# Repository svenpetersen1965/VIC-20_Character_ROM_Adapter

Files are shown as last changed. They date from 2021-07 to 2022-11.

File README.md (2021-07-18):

# VIC-20 Character ROM Adapter
A character ROM adapter for the Commodore VIC-20 for 27C64...512 EPROMs. It supports the usage of the 2nd 2332 ROM chip select for address decoding (which the <a href="https://github.com/svenpetersen1965/C64-CHARSET-Adaptor-Switch">C64 Character ROM Adapter</a> does not do.

It is configurable via solder bridges and can be configured as a C64 character ROM adapter, as well. It fits all VIC-20 mainboards and all C64 mainboards. It is a good solution for the C64 short board and a working solution for the C64 long boards. It might collide with a optional kernal adapter on the long boards, though, so the recommended solution for those is still the <a href="https://github.com/svenpetersen1965/C64-CHARSET-Adaptor-Switch">C64 Character ROM Adapter</a>.

The VIC-20 Character ROM Adapter was mainly created to provide a solution for the <a href="https://www.tindie.com/products/bobsbits/vicky-twenty-commodore-vic-20-pcb-replica/">Vicky Twenty</a> VIC-20 replica.

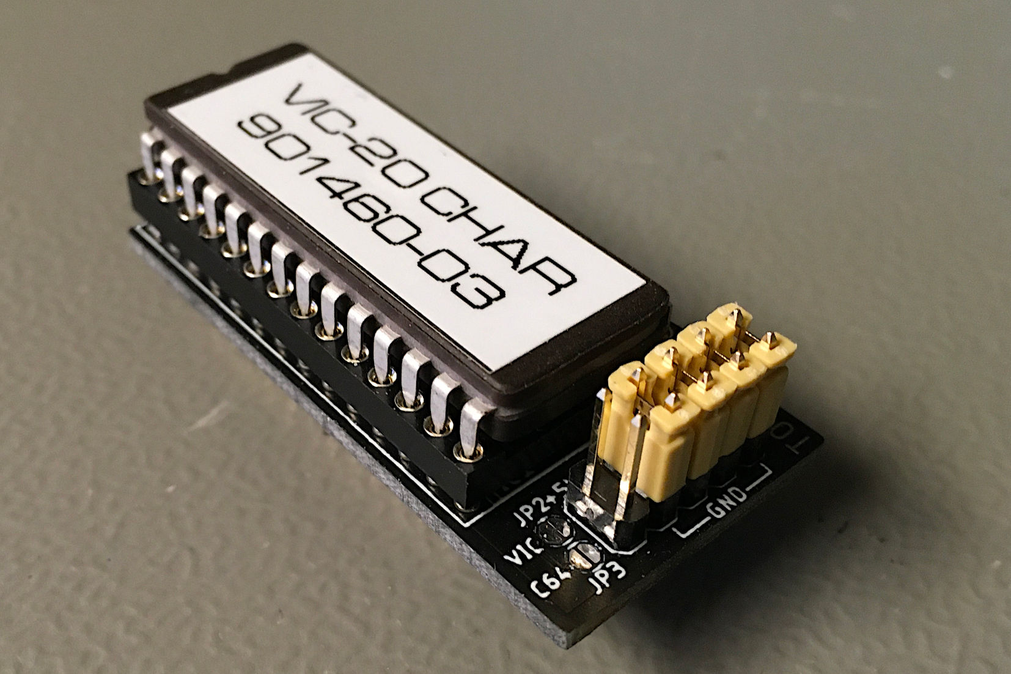
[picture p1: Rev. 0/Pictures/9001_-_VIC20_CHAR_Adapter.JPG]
VIC-20 Character ROM Adapter


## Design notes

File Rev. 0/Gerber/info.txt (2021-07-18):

      
       Board: VIC-20_CHARSET_adapter
       Rev.:  0
  
       Files:
       ======
  
       All Gerber files are generated in extended gerber format (RS274X)
       *.TOP        : Film top copper
       *.BOT        :  -"- bottom copper
       *.STC        :  -"- top soldermask 
       *.STS        :  -"- bottom soldermask
       *.PLC        :  -"- silk screen top
       *.PLS        :  -"- silk screen bottom
       *.CRC        :  -"- cream top
       *.DK         : Drills plated Through (Excellon)
       *.NDK        : Drills not plated Through (Excellon)
       *.OUT        : Board outline

       Board Size:
       ===========
       Length     :   45.0 mm
       Width      :   22.0 mm
       Thickness  :   1.6 mm
       Material   :   FR 4
       Copper     :   35 um
       Surface    :   HASL
       
       Remarks:
       ========

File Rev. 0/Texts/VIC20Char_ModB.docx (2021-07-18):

Commodore VIC-20 Character ROM Adapter Rev. 0

Module Description

The character ROM 901450-03 of the Commodore VIC-20 is a 2332 type ROM. Other than in the C64, it makes use of the 2nd chip select for address decoding. Thus, the C64 character ROM adapter (project number 126) is not suitable for the VIC-20.

The VIC-20 Character ROM adapter fixes this. Also, the geometry is different from the C64 Character ROM adapter to make it fit into ASSY250403, where it is pretty close to the RF-shield of the video circuit.

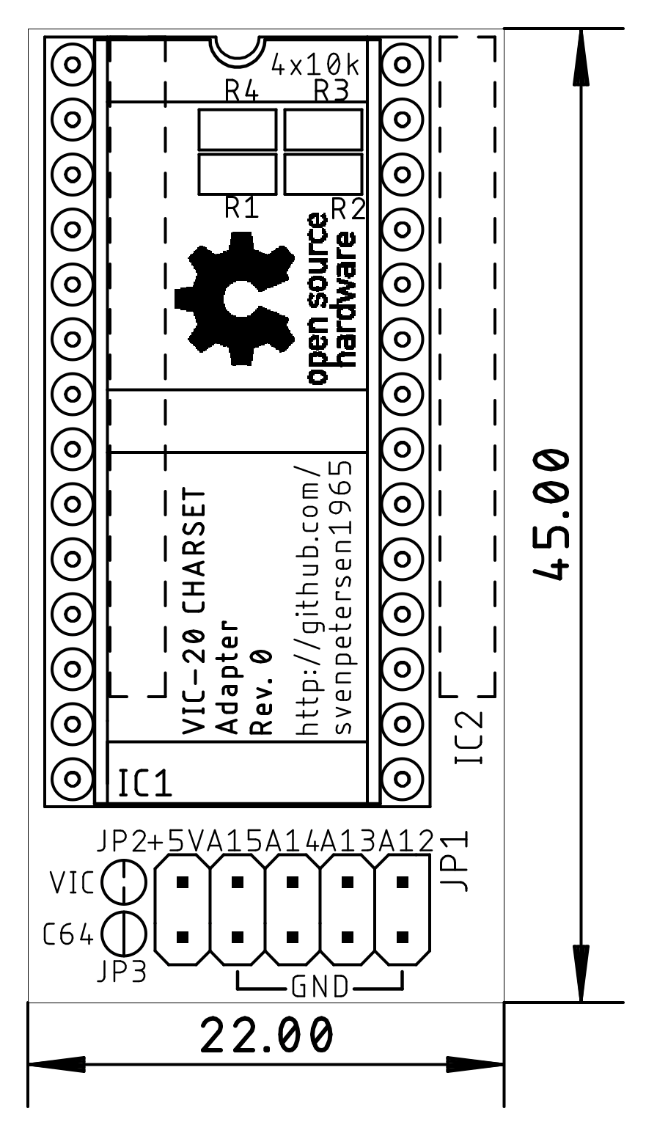
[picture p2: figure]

Figure 1: Dimensions

The VIC-20 Character ROM adapter can be configured to work with the C64 with solder bridges (JP2 & JP3). The default configuration is the VIC-20 mode, though. For the C64 short board, it fits mechanically quite well, due to the alignment of the socket/PCB to the left side or the ROM socket on the C64.

Computer | JP2 | JP3
VIC-20 | closed | open
C62 | open | closed

Table 1: Compatibility configuration

This pin-header JP1 is connected in a way, that the selection can either be accomplished with standard 2.54mm jumper bridges, DIP-switches, hex-encoding switches or a microcontroller like an Arduino etc.

Signal | Pin | Pin | Signal
A12 | 1 | 2 | GND
A13 | 3 | 4 | GND
A14 | 5 | 6 | GND
A15 | 7 | 8 | GND
+5V | 9 | 10 | n.c.

Table 2: Jumper (JP1) for Bank Selection

The +5V pin is suitable to provide supply voltage to a microcontroller.

# Bank Selection

The desired CHARACTER SET is selected at JP1. For the pinout refer to Table 2. The jumper is installed (vertically) in a way, that it connects the address line with the GND potential.

A15 | A14 | A13 | A12 | 4k Block | | Addr. Offset
set | set | set | set | | #0 | 0x0000
set | set | set | open | | #1 | 0x1000
set | set | open | set | | #2 | 0x2000
set | set | open | open | | #3 | 0x3000
set | open | set | set | | #4 | 0x4000
set | open | set | open | | #5 | 0x5000
set | open | open | set | | #6 | 0x6000
set | open | open | open | | #7 | 0x7000
open | set | set | set | | #8 | 0x8000
open | set | set | open | | #9 | 0x9000
open | set | open | set | | #10 | 0xA000
open | set | open | open | | #11 | 0xB000
open | open | set | set | | #12 | 0xC000
open | open | set | open | | #13 | 0xD000
open | open | open | set | | #14 | 0xE000
open | open | open | open | | #15 | 0xF000

Table 3: Selection of EPROM memory blocks (@JP1)

A set jumper corresponds to a LOW level (binary 0), an open jumper to a HIGH level. Do not confuse the C64 memory address and the EPROM memory address. They have the address Bit A0 to A11 in common, but the rest is different. Each of the 4k blocks appears between address $D000 and $DFFF of the C64.

# Compatibility of EPROMs

Although a 27C512 type EPROM is recommended, other types of EPROMs can be installed:

EPROM | Size | Capacity
27C64 | 8k | 2x Character Sets
27C128 | 16k | 4x Character Sets
27C256 | 32k | 8x Character Sets
27C512 | 64k | 16x Character Sets

Table 4: Capacity of EPROM types

Those EPROMs are pin compatible, the jumpers, that have no function, due to the size, have to stay open.

EPROM | Size | A15 | A14 | A13 | A12
27C512 | 64kx8 | ☑ | ☑ | ☑ | ☑
27C256 | 32kx8 | open | ☑ | ☑ | ☑
27C128 | 16kx8 | open | open | ☑ | ☑
27C64 | 8kx8 | open | open | open | ☑

Table 5: Settings per EPROM type

☑: The jumper can be open or closed, depending on the desired selection.

In case Vpp is located at a dedicated pin (pin 1), A15 has no effect anymore. A HIGH level is recommended, the corresponding jumper is open. The /PGM Pin should be set HIGH, this is accomplished by an open jumper for A14.

27C64
| 27C128
| | 27C256
| | | 27C512
| | | | SOCKET
Vpp | Vpp | Vpp | A15 | 1 | A15 | VCC | 28 | VCC | VCC | VCC | VCC
A12 | A12 | A12 | A12 | 2 | A12 | A14 | 27 | A14 | A14 | /PGM | /PGM
A7 | A7 | A7 | A7 | 3 | A7 | A13 | 26 | A13 | A13 | A13 | n.c.
A6 | A6 | A6 | A6 | 4 | A6 | A8 | 25 | A8 | A8 | A8 | A8
A5 | A5 | A5 | A5 | 5 | A5 | A9 | 24 | A9 | A9 | A9 | A9
A4 | A4 | A4 | A4 | 6 | A4 | A11 | 23 | A11 | A11 | A11 | A11
A3 | A3 | A3 | A3 | 7 | A3 | /OE | 22 | /G/Vpp | /G | /G | /G
A2 | A2 | A2 | A2 | 8 | A2 | A10 | 21 | A10 | A10 | A10 | A10
A1 | A1 | A1 | A1 | 9 | A1 | GND | 20 | /E | /E | /E | /E
A0 | A0 | A0 | A0 | 10 | A0 | D7 | 19 | D7 | D7 | D7 | D7
D0 | D0 | D0 | D0 | 11 | D0 | D6 | 18 | D6 | D6 | D6 | D6
D1 | D1 | D1 | D1 | 12 | D1 | D5 | 17 | D5 | D5 | D5 | D5
D2 | D2 | D2 | D2 | 13 | D2 | D4 | 16 | D4 | D4 | D4 | D4
GND | GND | GND | GND | 14 | GND | D3 | 15 | D3 | D3 | D3 | D3

Table 6: EPROM pin compatibility

# Using parallel EEPROMs

There are parallel EPROMs, which fit into the EPROM sockets. They do not require erasing with a UV eraser, like EPROMs, but the price is higher.

Since they can be written, which is controlled by the signal, but the Super Expander II cartridge is lacking of this functionality, this signal has to be HIGH (inactive). The 28C256 has the A14 signal connected to Pin 1, which is A15 of the EEPROM socket. This is no problem, but it has to be kept in mind, that the jumper for A15 has effect on the bank select A14 of the EPROM.

28C64
| 28C256
| | SOCKET
n.c. | A14 | 1 | A15 | VCC | 28 | VCC | VCC
A12 | A12 | 2 | A12 | A14 | 27 | /WE | /WE
A7 | A7 | 3 | A7 | A13 | 26 | A13 | n.c
A6 | A6 | 4 | A6 | A8 | 25 | A8 | A8
A5 | A5 | 5 | A5 | A9 | 24 | A9 | A9
A4 | A4 | 6 | A4 | A11 | 23 | A11 | A11
A3 | A3 | 7 | A3 | /OE | 22 | /G/Vpp | /OE
A2 | A2 | 8 | A2 | A10 | 21 | A10 | A10
A1 | A1 | 9 | A1 | GND | 20 | /E | /CE
A0 | A0 | 10 | A0 | D7 | 19 | D7 | D7
D0 | D0 | 11 | D0 | D6 | 18 | D6 | D6
D1 | D1 | 12 | D1 | D5 | 17 | D5 | D5
D2 | D2 | 13 | D2 | D4 | 16 | D4 | D4
GND | GND | 14 | GND | D3 | 15 | D3 | D3

Table 7: EEPROM pin compatibility

EEPROM | Size | A15 | A14 | A13
28C256 | 32kx8 | =A14 | OPEN | yes
28C64 | 8kx8 | OPEN | OPEN | OPEN

Table 8: Settings per EEPROM type

# Programming instructions

Character sets can be found here:

http://www.zimmers.net/anonftp/pub/cbm/firmware/computers/vic20/index.html or elsewhere. For instructions on setting up a complete multiple character ROM image, please refer to

https://github.com/svenpetersen1965/C64-Kernal-Adapter-Switch-Long-Board/blob/master/Rev.%200/pdf/C64_KernalSw_8k_v0.pdf

The description is about how to create a multiple Kernal ROM image, a multiple Character ROM image works pretty similar, except the size is only 4kB.

# Revision History

## Rev. 0

- Fully working Prototype.

VIC20Char_ModB.docx 18.07.2021 01:19 Drafted by Sven Petersen Page 2 of 2 Doc.-No.: 184-6-01-00

VIC20Char_ModB.docx 18.07.2021 01:19 Drafted by Sven Petersen Page 1 of 1 Doc.-No.: 000-6-00-00

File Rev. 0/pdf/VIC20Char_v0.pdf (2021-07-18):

# Project Documentation

## Commodore VIC-20 Character ROM Adapter

## Project number: 184

## Revision: 0

## Date: 18.07.2021

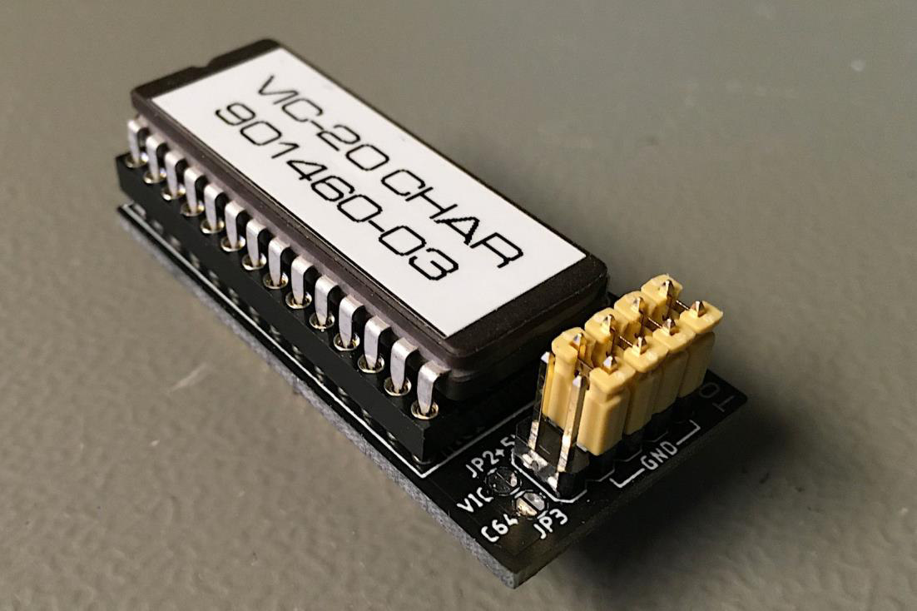
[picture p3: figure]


VIC20Char_ModB.docx | | 18.07.2021 01:19
Drafted by Sven Petersen | Page 1 of 5 | Doc.-No.: 184-6-01-00

### Commodore VIC-20 Character ROM Adapter Rev. 0

### Module Description

The character ROM 901450-03 of the Commodore VIC-20 is a 2332 type ROM. Other than in the C64, it makes use of the 2nd chip select for address decoding. Thus, the C64 character ROM adapter (project number 126) is not suitable for the VIC-20.

The VIC-20 Character ROM adapter fixes this. Also, the geometry is different from the C64 Character ROM adapter to make it fit into ASSY250403, where it is pretty close to the RF-shield of the video circuit.

Figure 1: Dimensions

The VIC-20 Character ROM adapter can be configured to work with the C64 with solder bridges (JP2 & JP3). The default configuration is the VIC-20 mode, though. For the C64 short board, it fits mechanically quite well, due to the alignment of the socket/PCB to the left side or the ROM socket on the C64.

Computer | JP2 | JP3
VIC-20 | closed | open
C62 | open | closed
Table 1: Compatibility configuration

VIC20Char_ModB.docx | | 18.07.2021 01:19
Drafted by Sven Petersen | Page 2 of 5 | Doc.-No.: 184-6-01-00

This pin-header JP1 is connected in a way, that the selection can either be accomplished with standard 2.54mm jumper bridges, DIP-switches, hex-encoding switches or a microcontroller like an Arduino etc.

Signal Pin | Pin Signal
A12 | 1 | 2 | GND
A13 | 3 | 4 | GND
A14 | 5 | 6 | GND
A15 | 7 | 8 | GND
+5V | 9 | 10 | n.c.
Table 2: Jumper (JP1) for Bank Selection

The +5V pin is suitable to provide supply voltage to a microcontroller.

## Bank Selection

The desired CHARACTER SET is selected at JP1. For the pinout refer to Table 2. The jumper is installed (vertically) in a way, that it connects the address line with the GND potential.

A15 | A14 | A13 | A12 | 4k Block | Addr. Offset
set | set | set | set | #0 | 0x0000
set | set | set | open | #1 | 0x1000
set | set | open | set | #2 | 0x2000
set | set | open | open | #3 | 0x3000
set | open | set | set | #4 | 0x4000
set | open | set | open | #5 | 0x5000
set | open | open | set | #6 | 0x6000
set | open | open | open | #7 | 0x7000
open | set | set | set | #8 | 0x8000
open | set | set | open | #9 | 0x9000
open | set | open | set | #10 | 0xA000
open | set | open | open | #11 | 0xB000
open | open | set | set | #12 | 0xC000
open | open | set | open | #13 | 0xD000
open | open | open | set | #14 | 0xE000
open | open | open | open | #15 | 0xF000
Table 3: Selection of EPROM memory blocks (@JP1)

A set jumper corresponds to a LOW level (binary 0), an open jumper to a HIGH level. Do not confuse the C64 memory address and the EPROM memory address. They have the address Bit A0 to A11 in common, but the rest is different. Each of the 4k blocks appears between address $D000 and $DFFF of the C64.

VIC20Char_ModB.docx | | 18.07.2021 01:19
Drafted by Sven Petersen | Page 3 of 5 | Doc.-No.: 184-6-01-00

## Compatibility of EPROMs

Although a 27C512 type EPROM is recommended, other types of EPROMs can be installed:

EPROM | Size | Capacity
27C64 | 8k | 2x Character Sets
27C128 | 16k | 4x Character Sets
27C256 | 32k | 8x Character Sets
27C512 | 64k | 16x Character Sets
Table 4: Capacity of EPROM types

Those EPROMs are pin compatible, the jumpers, that have no function, due to the size, have to stay open.

EPROM | Size | A15 | A14 | A13 | A12
27C512 | 64kx8 | ☑ | ☑ | ☑ | ☑
27C256 | 32kx8 | open | ☑ | ☑ | ☑
27C128 | 16kx8 | open | open | ☑ | ☑
27C64 | 8kx8 | open | open | open | ☑
Table 5: Settings per EPROM type

☑: The jumper can be open or closed, depending on the desired selection.

In case Vpp is located at a dedicated pin (pin 1), A15 has no effect anymore. A HIGH level is recommended, the corresponding jumper is open. The /PGM Pin should be set HIGH, this is accomplished by an open jumper for A14.

27C64
| 27C128
| 27C256
| 27C512
| SOCKET
Vpp | Vpp | Vpp | A15 | 1 | A15 | VCC | 28 | VCC | VCC | VCC | VCC
A12 | A12 | A12 | A12 | 2 | A12 | A14 | 27 | A14 | A14 | /PGM | /PGM
A7 | A7 | A7 | A7 | 3 | A7 | A13 | 26 | A13 | A13 | A13 | n.c.
A6 | A6 | A6 | A6 | 4 | A6 | A8 | 25 | A8 | A8 | A8 | A8
A5 | A5 | A5 | A5 | 5 | A5 | A9 | 24 | A9 | A9 | A9 | A9
A4 | A4 | A4 | A4 | 6 | A4 | A11 | 23 | A11 | A11 | A11 | A11
A3 | A3 | A3 | A3 | 7 | A3 | /OE | 22 | /G/Vpp | /G | /G | /G
A2 | A2 | A2 | A2 | 8 | A2 | A10 | 21 | A10 | A10 | A10 | A10
A1 | A1 | A1 | A1 | 9 | A1 | GND | 20 | /E | /E | /E | /E
A0 | A0 | A0 | A0 | 10 | A0 | D7 | 19 | D7 | D7 | D7 | D7
D0 | D0 | D0 | D0 | 11 | D0 | D6 | 18 | D6 | D6 | D6 | D6
D1 | D1 | D1 | D1 | 12 | D1 | D5 | 17 | D5 | D5 | D5 | D5
D2 | D2 | D2 | D2 | 13 | D2 | D4 | 16 | D4 | D4 | D4 | D4
GND | GND | GND | GND | 14 | GND | D3 | 15 | D3 | D3 | D3 | D3
Table 6: EPROM pin compatibility

VIC20Char_ModB.docx | | 18.07.2021 01:19
Drafted by Sven Petersen | Page 4 of 5 | Doc.-No.: 184-6-01-00

## Using parallel EEPROMs

There are parallel EPROMs, which fit into the EPROM sockets. They do not require erasing with a UV eraser, like EPROMs, but the price is higher.

Since they can be written, which is controlled by the WE signal, but the Super Expander II cartridge is lacking of this functionality, this signal has to be HIGH (inactive). The 28C256 has the A14 signal connected to Pin 1, which is A15 of the EEPROM socket. This is no problem, but it has to be kept in mind, that the jumper for A15 has effect on the bank select A14 of the EPROM.

28C64
| 28C256
| SOCKET
n.c. | A14 | 1 | A15 | VCC | 28 | VCC | VCC
A12 | A12 | 2 | A12 | A14 | 27 | /WE | /WE
A7 | A7 | 3 | A7 | A13 | 26 | A13 | n.c
A6 | A6 | 4 | A6 | A8 | 25 | A8 | A8
A5 | A5 | 5 | A5 | A9 | 24 | A9 | A9
A4 | A4 | 6 | A4 | A11 | 23 | A11 | A11
A3 | A3 | 7 | A3 | /OE | 22 | /G/Vpp | /OE
A2 | A2 | 8 | A2 | A10 | 21 | A10 | A10
A1 | A1 | 9 | A1 | GND | 20 | /E | /CE
A0 | A0 | 10 | A0 | D7 | 19 | D7 | D7
D0 | D0 | 11 | D0 | D6 | 18 | D6 | D6
D1 | D1 | 12 | D1 | D5 | 17 | D5 | D5
D2 | D2 | 13 | D2 | D4 | 16 | D4 | D4
GND | GND | 14 | GND | D3 | 15 | D3 | D3
Table 7: EEPROM pin compatibility
EEPROM | Size | A15 | A14 | A13
28C256 | 32kx8 | =A14 | OPEN | yes
28C64 | 8kx8 | OPEN | OPEN | OPEN
Table 8: Settings per EEPROM type

## Programming instructions

Character sets can be found here:

http://www.zimmers.net/anonftp/pub/cbm/firmware/computers/vic20/index.html or elsewhere. For instructions on setting up a complete multiple character ROM image, please refer to

https://github.com/svenpetersen1965/C64-Kernal-Adapter-Switch-Long-Board/blob/master/Rev.%200/pdf/C64_KernalSw_8k_v0.pdf (https://github.com/svenpetersen1965/C64-Kernal-Adapter-Switch-Long-Board/blob/master/Rev.%200/pdf/C64_KernalSw_8k_v0.pdf)

The description is about how to create a multiple Kernal ROM image, a multiple Character ROM image works pretty similar, except the size is only 4kB.

VIC20Char_ModB.docx | | 18.07.2021 01:19
Drafted by Sven Petersen | Page 5 of 5 | Doc.-No.: 184-6-01-00

## Revision History

### Rev. 0

- Fully working Prototype.

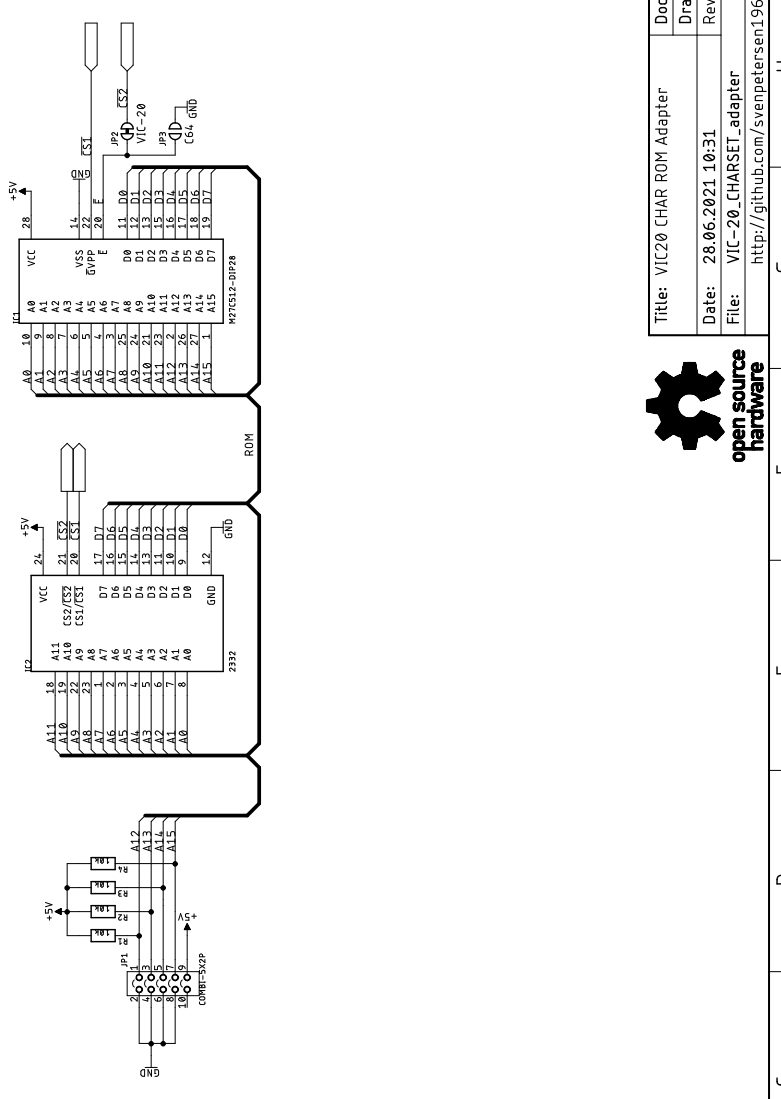
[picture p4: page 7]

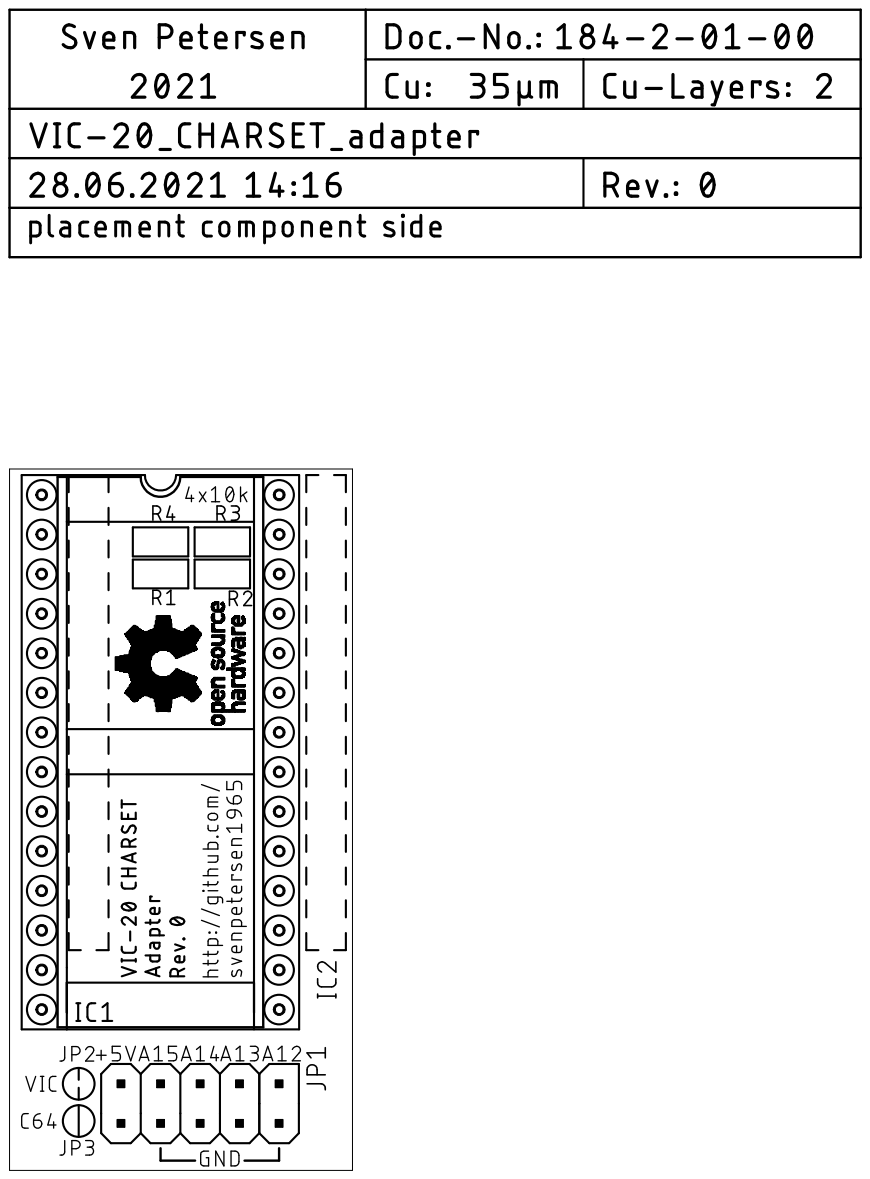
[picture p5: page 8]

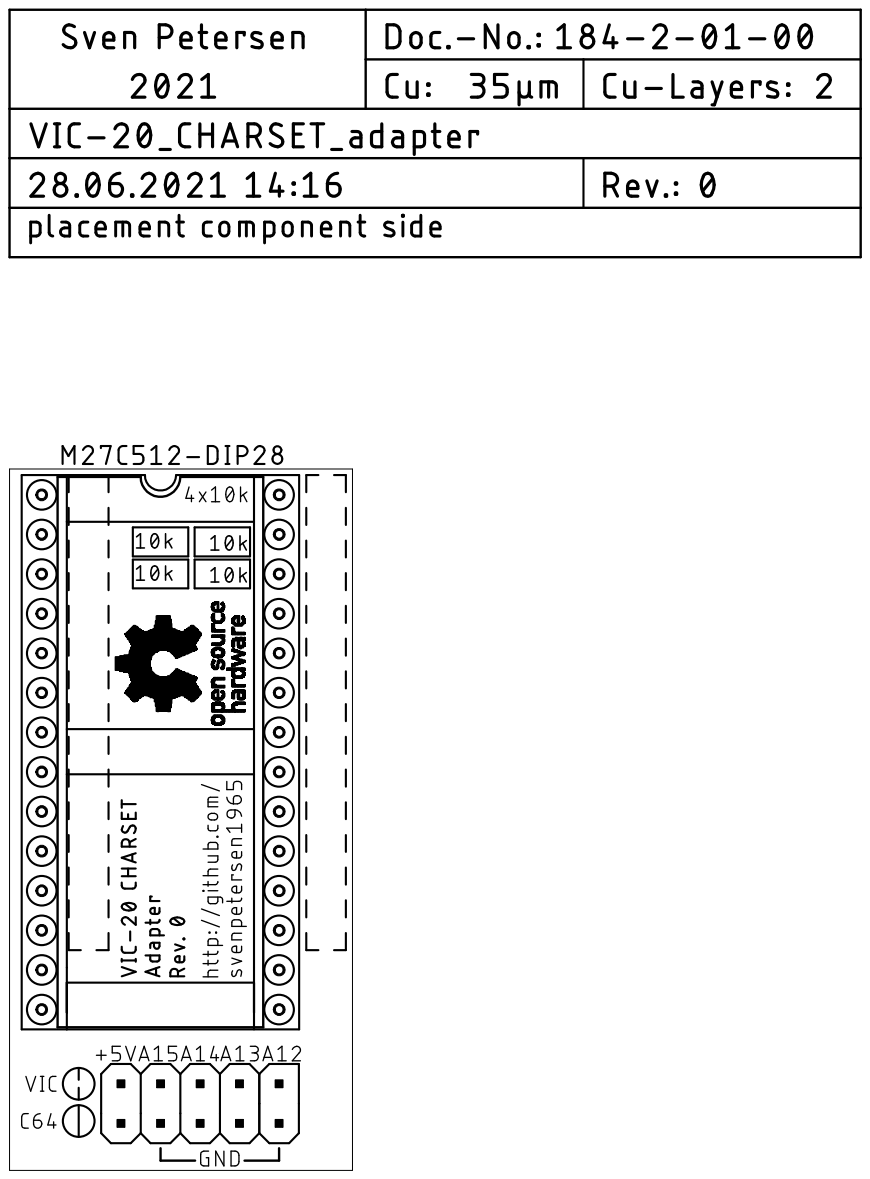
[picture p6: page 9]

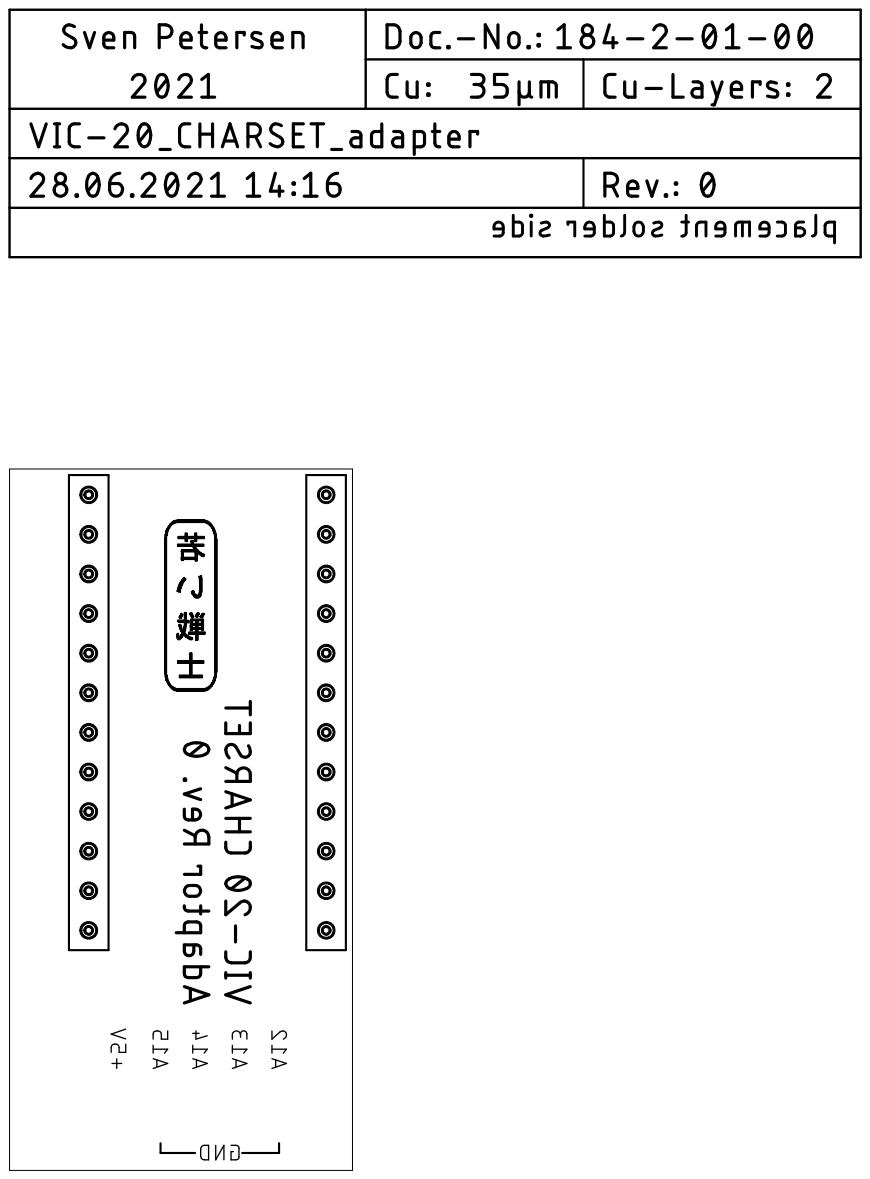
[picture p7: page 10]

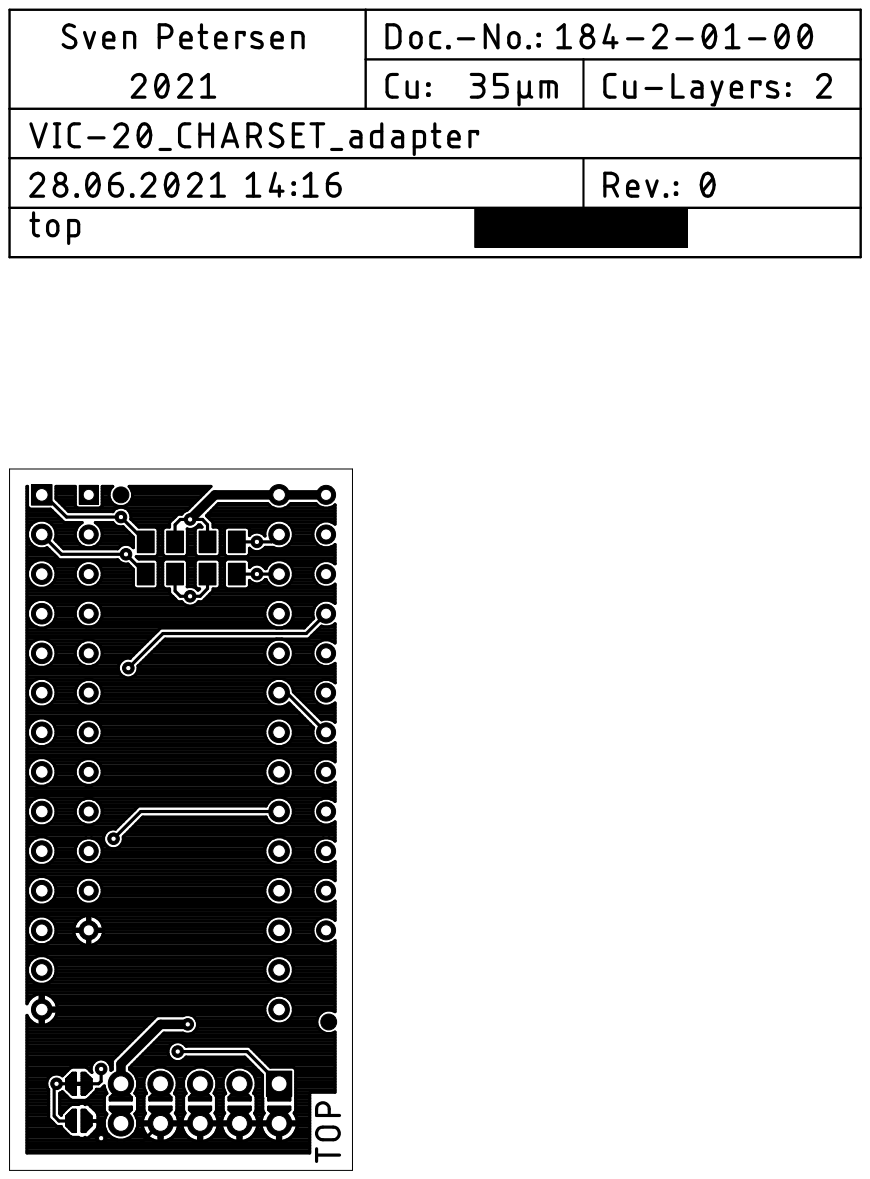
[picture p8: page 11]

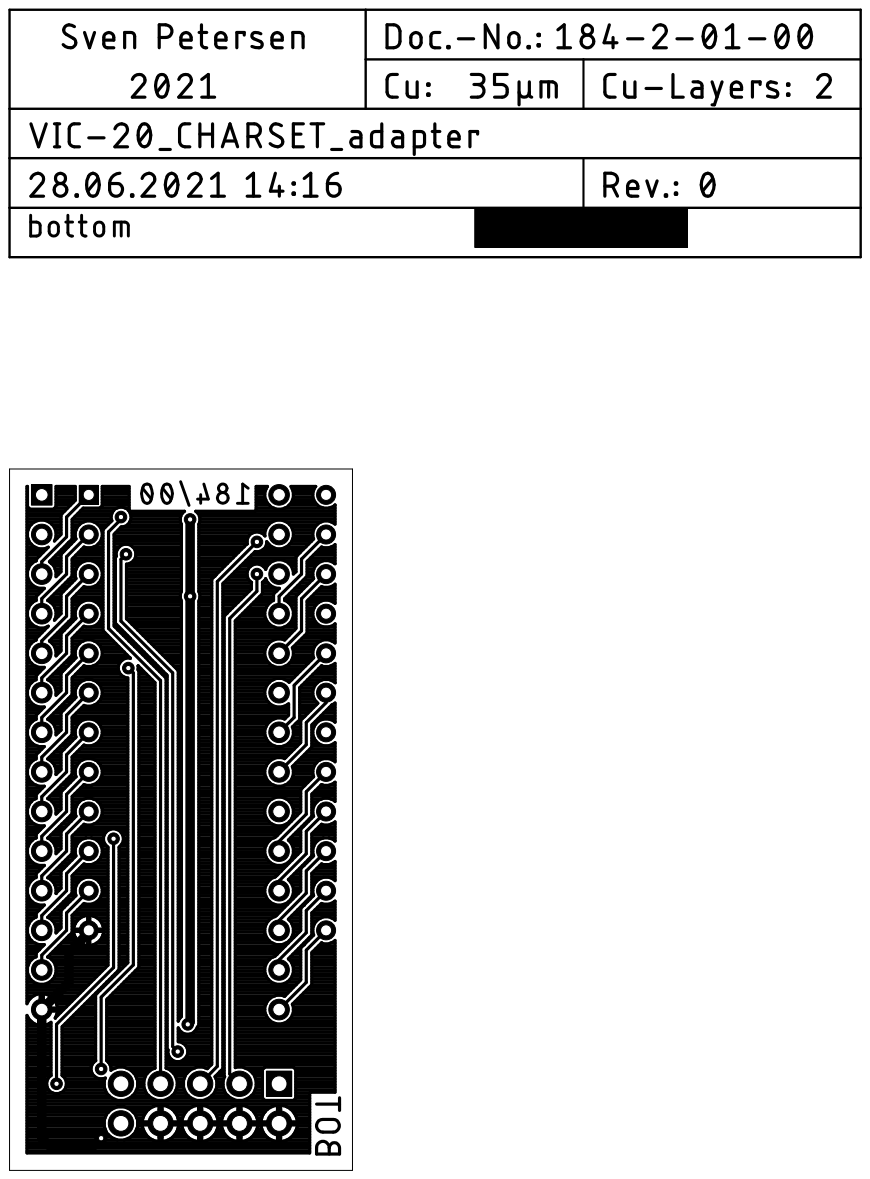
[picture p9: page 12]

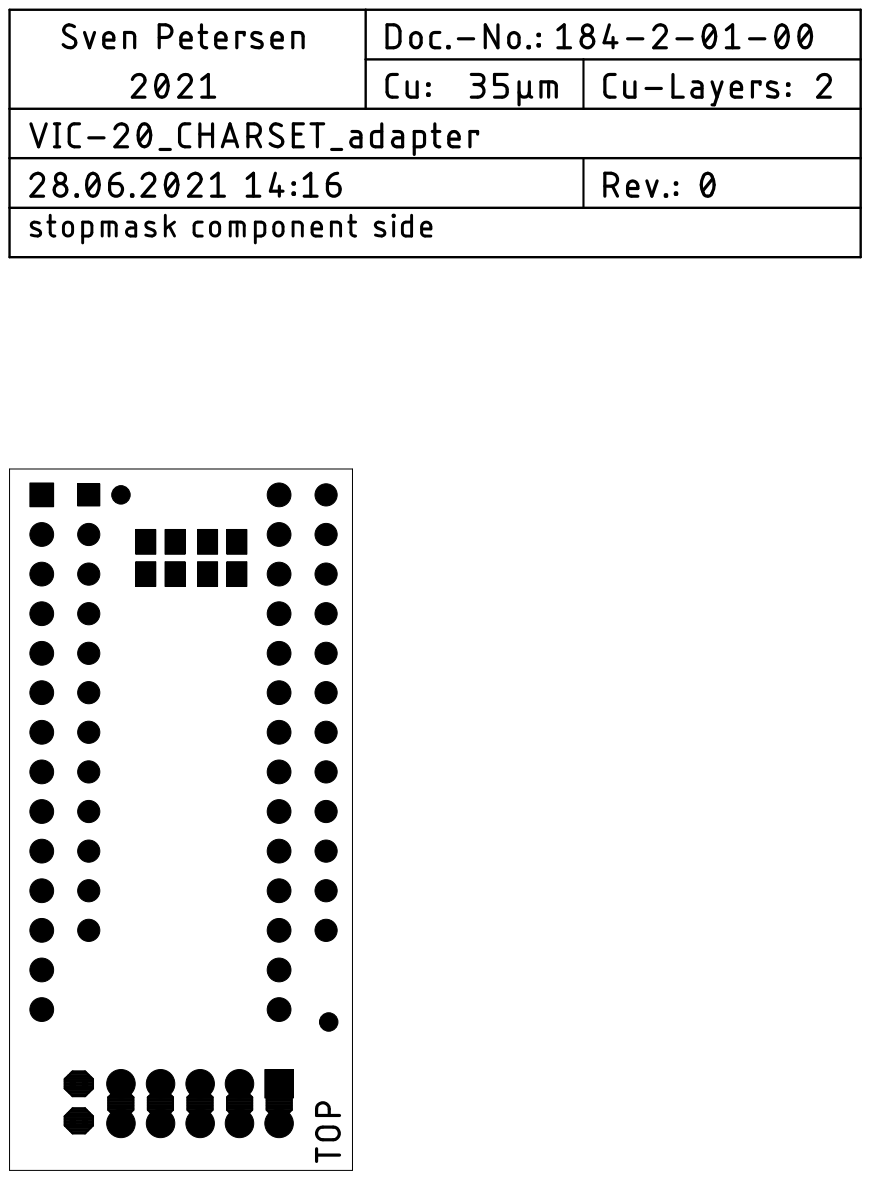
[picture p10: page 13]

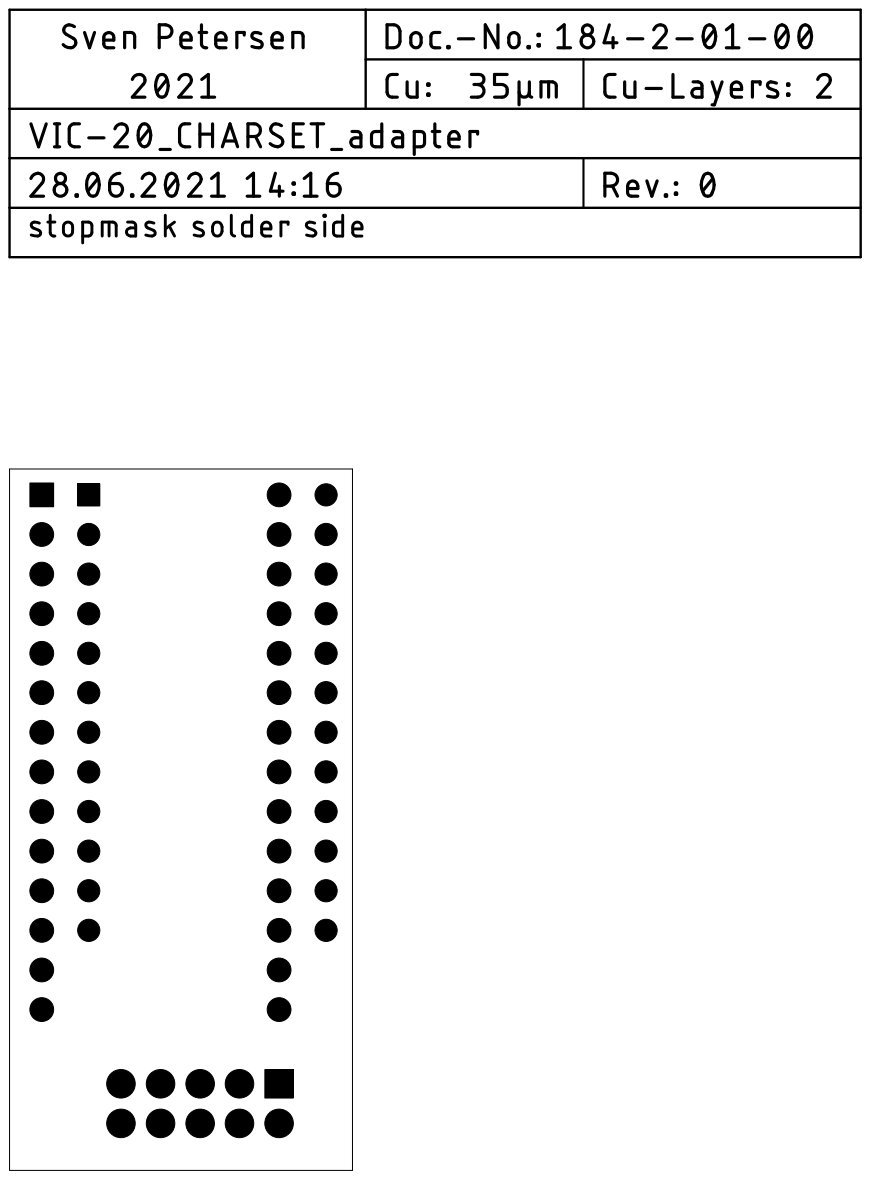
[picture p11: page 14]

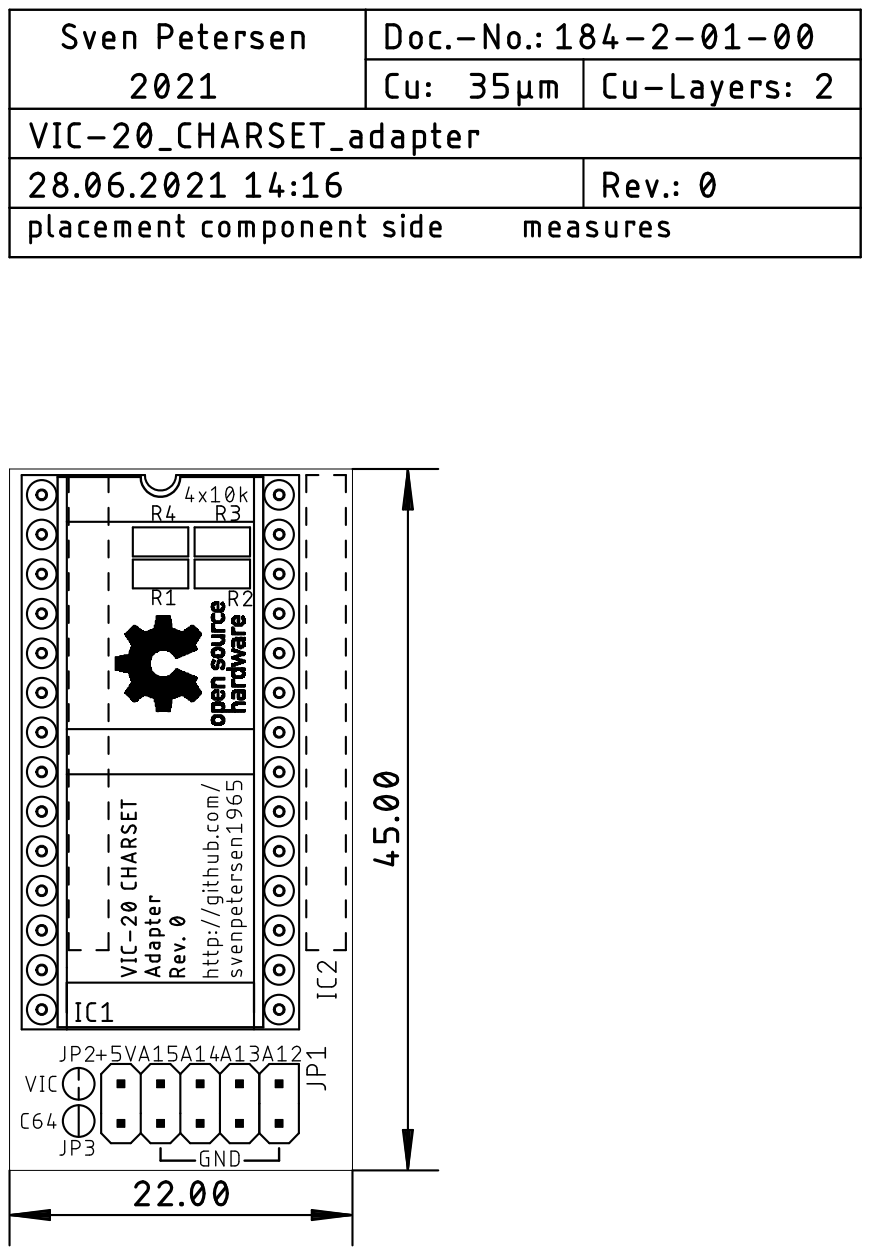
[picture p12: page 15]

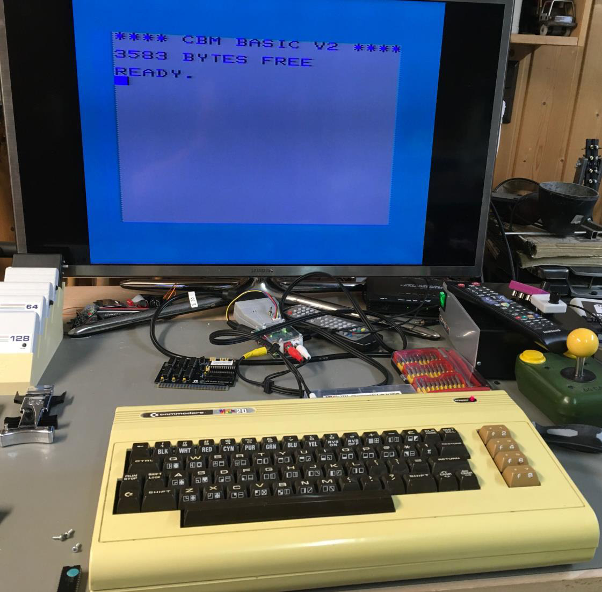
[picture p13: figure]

VIC20Char_Test.docx | | 18.07.2021 13:20
Drafted by Sven Petersen | Page 1 of 6 | Doc.-No.: 184-6-02-00

### Commodore VIC-20 Character ROM Adapter Rev. 0

### Test

## Test Setup

The Character ROM adapter Rev. 0 was electrically tested in two VIC-20:

### 1. A Vicky Twenty, which is a clone of ASSY250403 (the VIC-20 CR) 2. An original ASSY324003 (two prong VIC-20)

It was further mechanically tested in an original (non-functional) ASSY250403 with shield around the video circuit.

Finally, the adapter was reconfigured as a C64 adapter and tested with an

- ASSY250469 (short board)
- ASSY250425 (long board)

Figure 1: Test Setup with an ASSY324003 VIC-20

The screen shots were taken with a (cheap) CSL USB 2.0 Video Grabber.

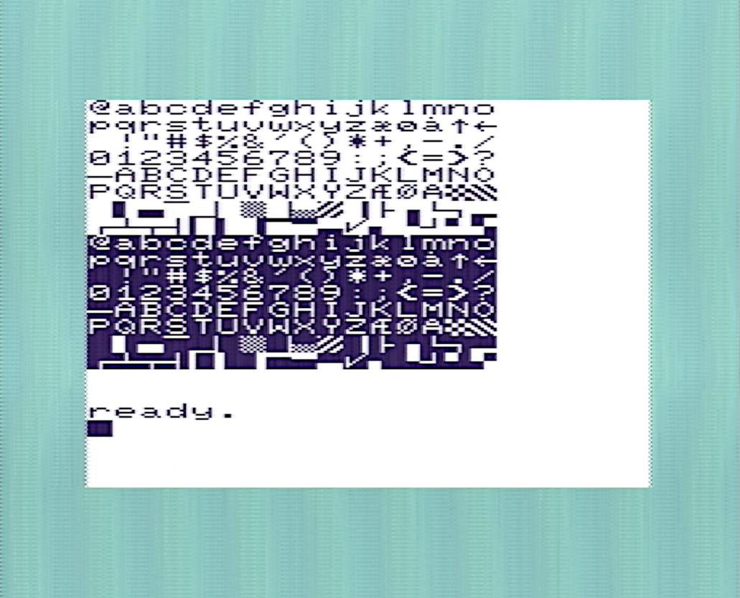
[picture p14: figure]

VIC20Char_Test.docx | | 18.07.2021 13:20
Drafted by Sven Petersen | Page 2 of 6 | Doc.-No.: 184-6-02-00

## Test Execution

### Electrical testing

A ST 27C512 EPROM (120ns) was programmed with the original Commodore character sets:

- English/International
- Danish
- Swedish/Finnish
- VC-1001

Then installed in the Vicky Twenty. A test software was written, which puts all 256 characters on the screen.

The characters were displayed properly. Pulling/stetting jumpers resulted in switching character sets (the characteristic umlauts of the particular language became visible).
The special Japanese characters became visible when switching to upper/lower case characters.

Figure 2: Danish character set on a VIC-20

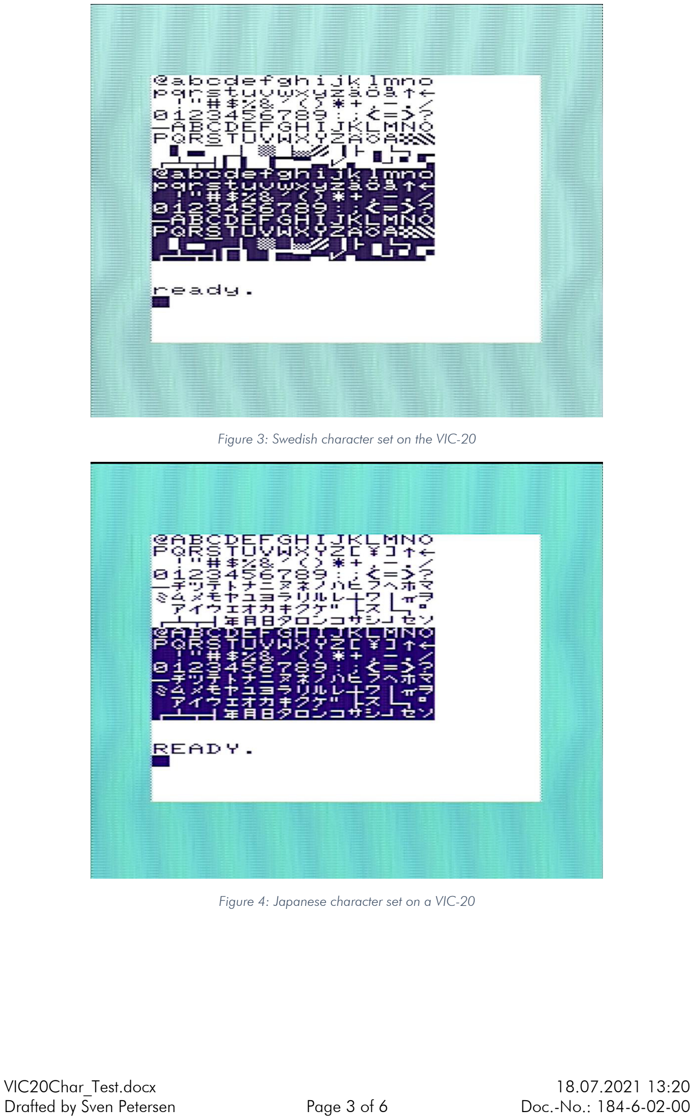
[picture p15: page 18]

VIC20Char_Test.docx | | 18.07.2021 13:20
Drafted by Sven Petersen | Page 3 of 6 | Doc.-No.: 184-6-02-00

Figure 3: Swedish character set on the VIC-20

Figure 4: Japanese character set on a VIC-20

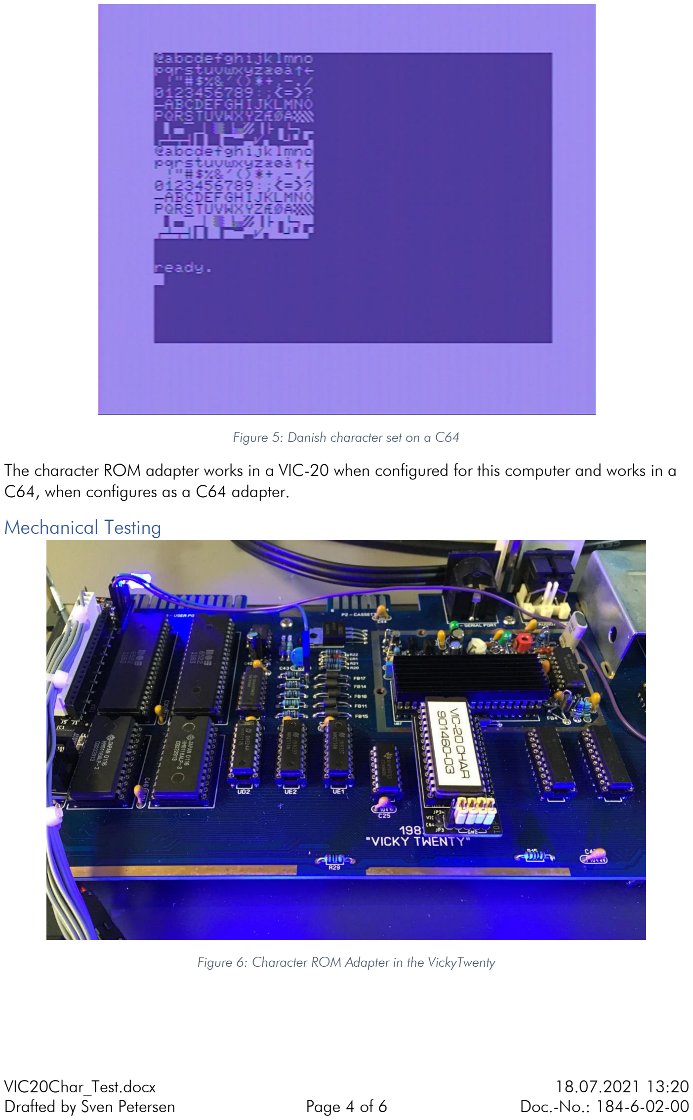
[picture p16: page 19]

VIC20Char_Test.docx | | 18.07.2021 13:20
Drafted by Sven Petersen | Page 4 of 6 | Doc.-No.: 184-6-02-00

Figure 5: Danish character set on a C64

The character ROM adapter works in a VIC-20 when configured for this computer and works in a C64, when configures as a C64 adapter.

### Mechanical Testing

Figure 6: Character ROM Adapter in the VickyTwenty

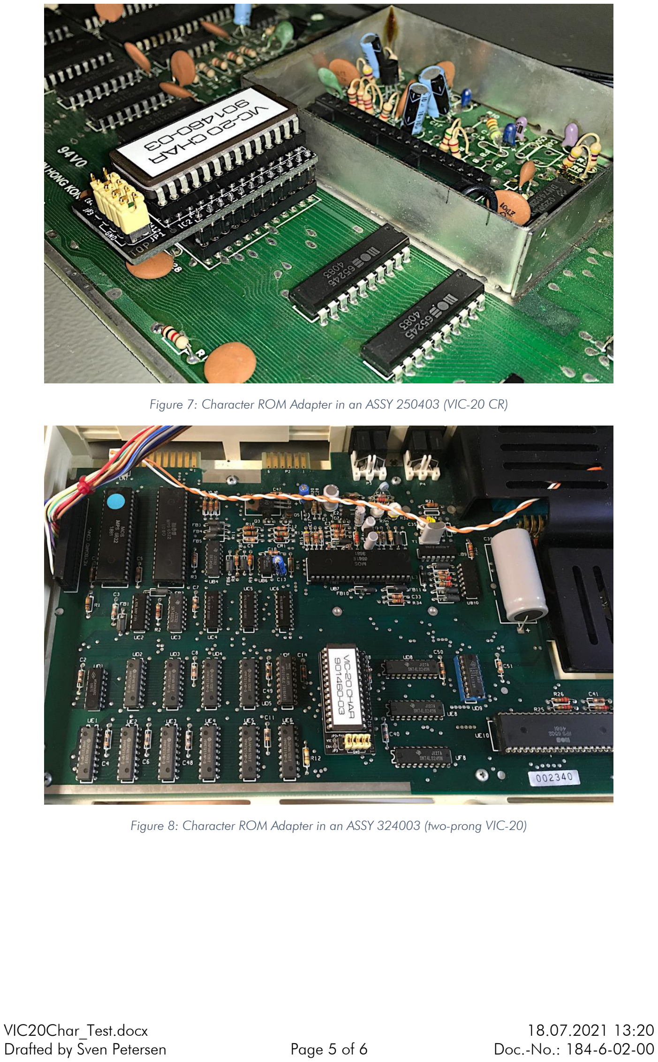
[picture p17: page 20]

VIC20Char_Test.docx | | 18.07.2021 13:20
Drafted by Sven Petersen | Page 5 of 6 | Doc.-No.: 184-6-02-00

Figure 7: Character ROM Adapter in an ASSY 250403 (VIC-20 CR)

Figure 8: Character ROM Adapter in an ASSY 324003 (two-prong VIC-20)

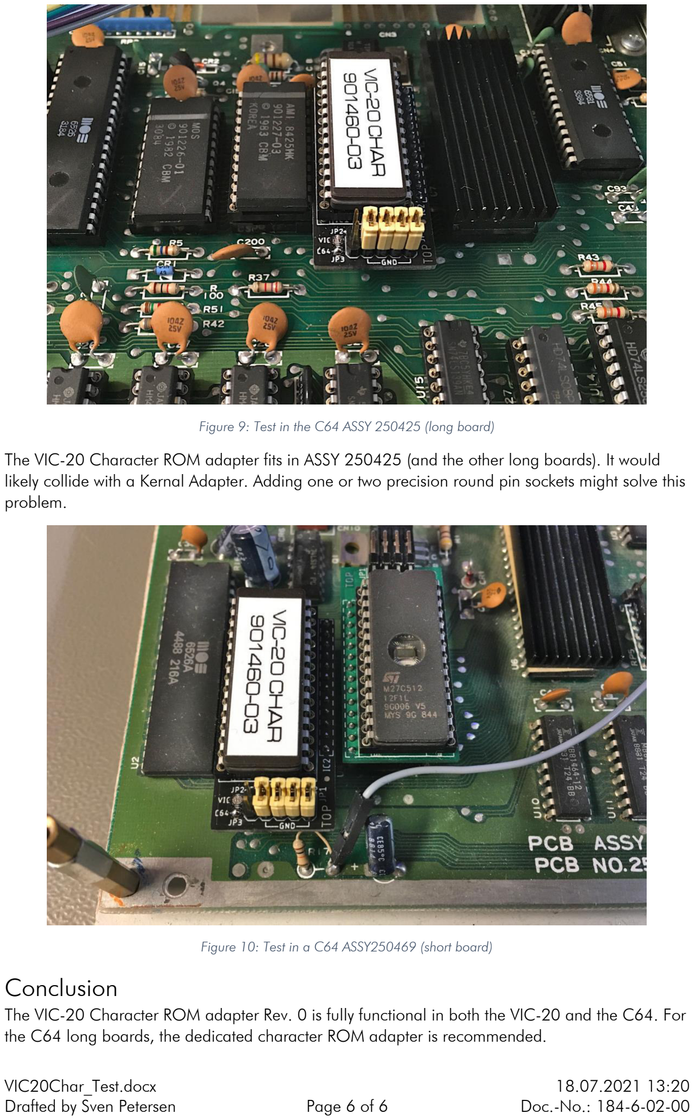
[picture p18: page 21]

VIC20Char_Test.docx | | 18.07.2021 13:20
Drafted by Sven Petersen | Page 6 of 6 | Doc.-No.: 184-6-02-00

Figure 9: Test in the C64 ASSY 250425 (long board)

The VIC-20 Character ROM adapter fits in ASSY 250425 (and the other long boards). It would likely collide with a Kernal Adapter. Adding one or two precision round pin sockets might solve this problem.

Figure 10: Test in a C64 ASSY250469 (short board)

## Conclusion

The VIC-20 Character ROM adapter Rev. 0 is fully functional in both the VIC-20 and the C64. For the C64 long boards, the dedicated character ROM adapter is recommended.

Pos. Qty Value Footprint Ref.-No. Comment

1 1 184-2-01-00 2 Layer PCB Rev. 0 2 layer, Cu 35µ, HASL, 45mm x 22mm, 1.6mm FR4

2 1 2x05pin, 2.54mm pitch 2x05 JP1 Standard pin header, 2.54mm pitch. E.g. Reichelt MPE 087-

2-010

3 4 Jumper 2.54mm (JP1) Jumpers for address selection (in case it is intended to

jumper the kenal selection)

4 4 10k 0805 R1, R2, R3, R3 SMD resistor

5 1 two Pinstrip, precision

round pins, cut to 12 pins

length

DIL24_SOCKET IC2 Precision Round pins mandatory! E.g. Reichelt BKL

10120540 or

10PCS Single Row 40Pin 2.54mm Round Male Pin Header

machined (https://www.ebay.de/itm/10PCS-Single-Row-40Pin-2-54mm-Round-Male-Pin-Header-machined/281821698031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)

6 1 M27C512 DIL28-6 IC1 EPROM 200ns or faster recommended, alternative sizes:

27C64, 27C128, 27C256 possible

7 1 DIP28 socket DIL28-6 (IC1) Precision round pin is recommended

## VIC-20 Character ROM Adapter Rev. 0

## Bill of Material Rev. 0.0

VIC20_Char_BOM_v0_0.xlsx

Drafted by Sven Petersen Page 1 of 1

18.07.2021 15:32
Doc.No.: 184-5-01-00.0

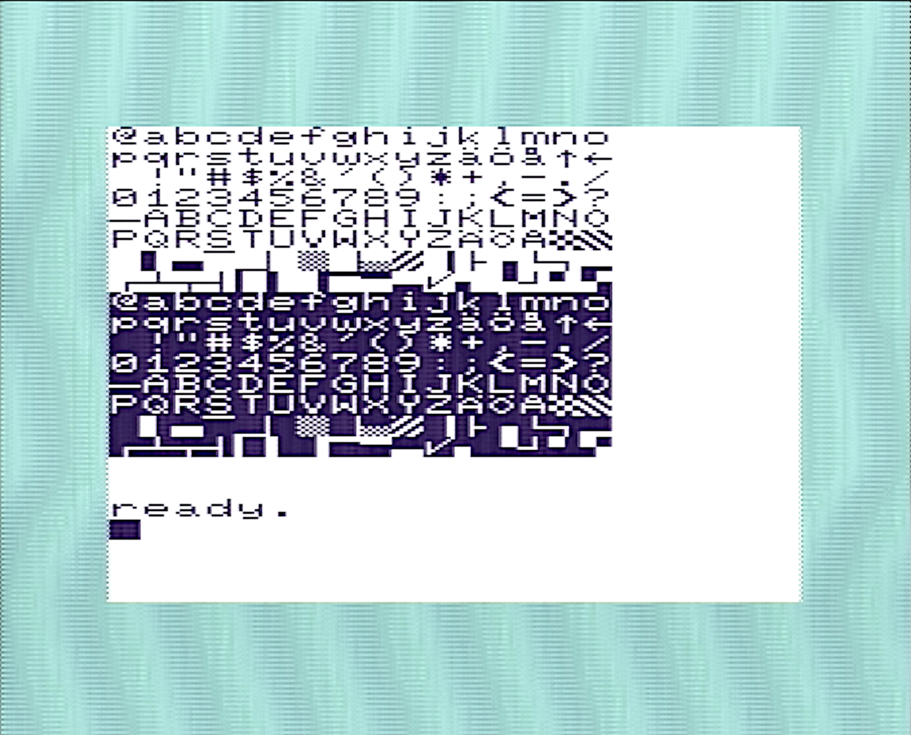
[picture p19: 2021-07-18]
Rev. 0/Pictures/SE_Char_VIC20.png

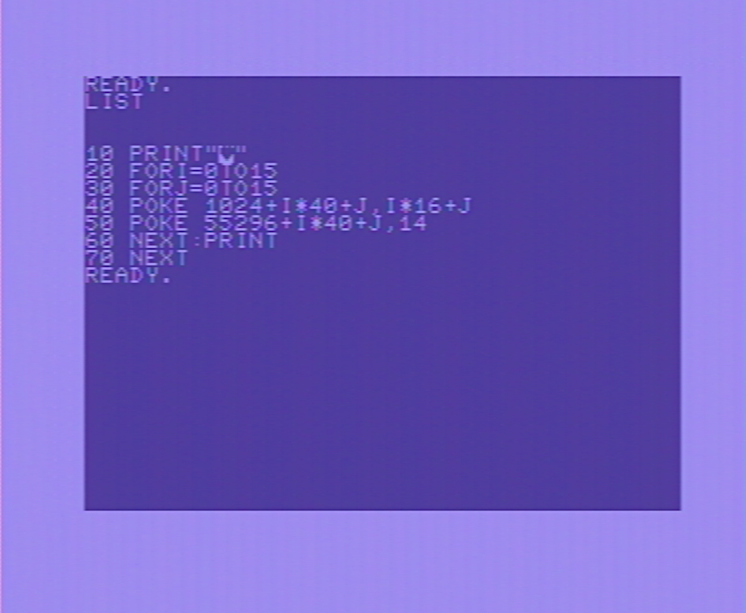
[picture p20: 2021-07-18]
Rev. 0/Pictures/C64_PRG.png

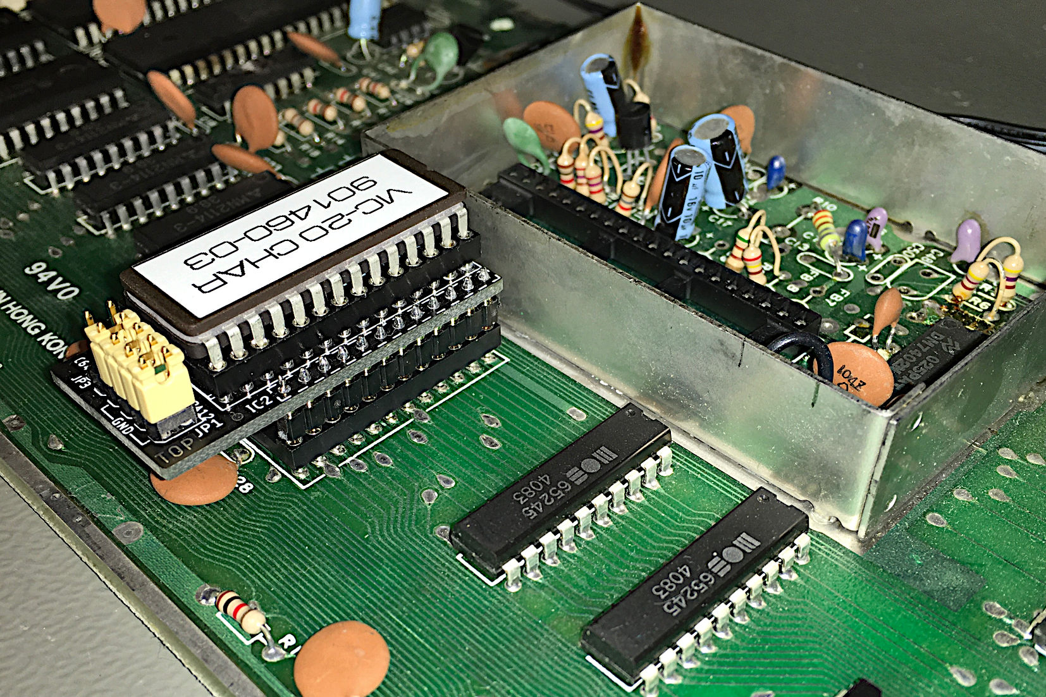
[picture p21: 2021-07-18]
Rev. 0/Pictures/9004_-_Fitting_in_ASSY250403.JPG

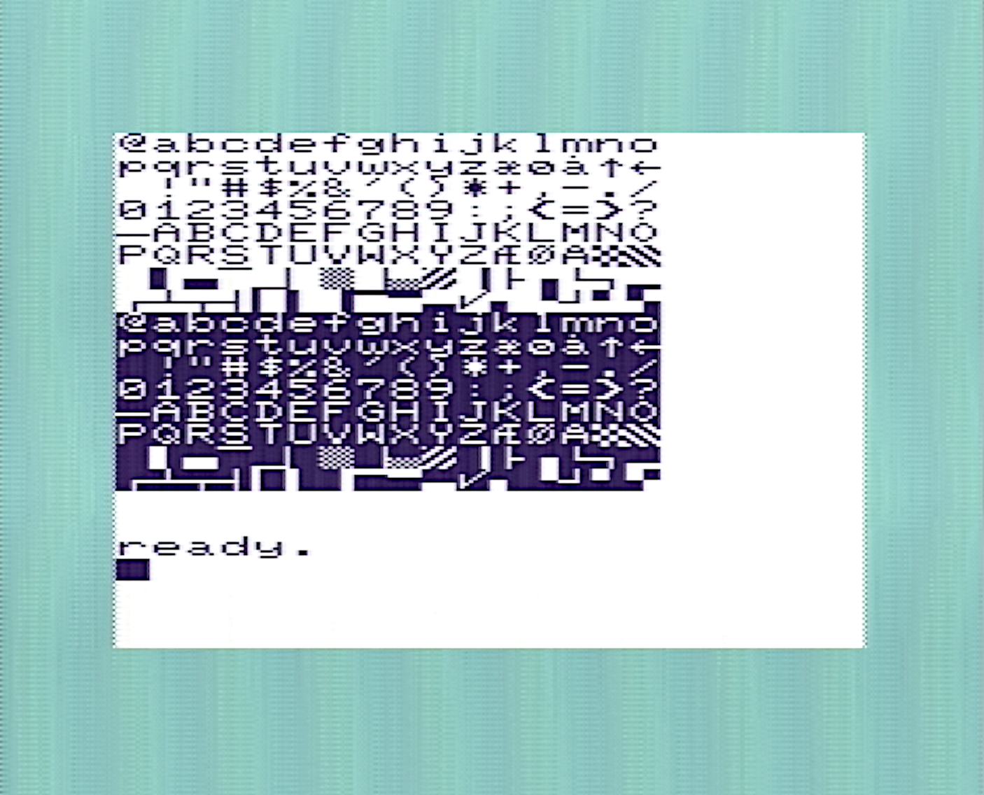
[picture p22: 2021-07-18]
Rev. 0/Pictures/DK_Char_VIC20.png

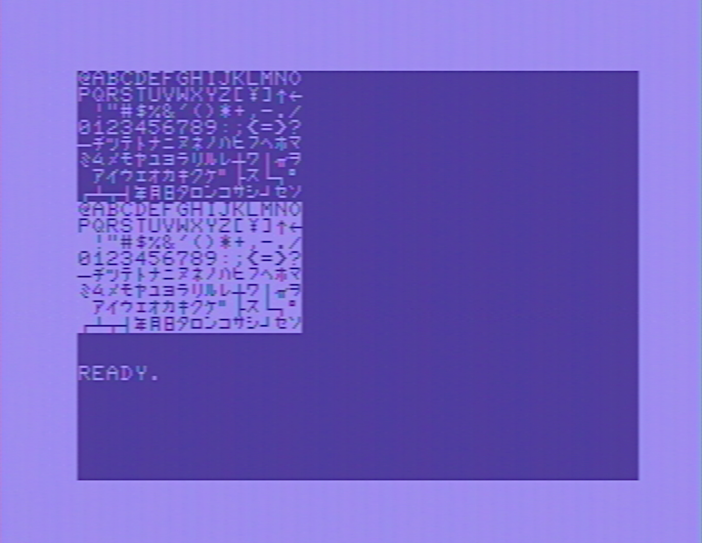
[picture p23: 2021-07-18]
Rev. 0/Pictures/JP_Char_C64.png

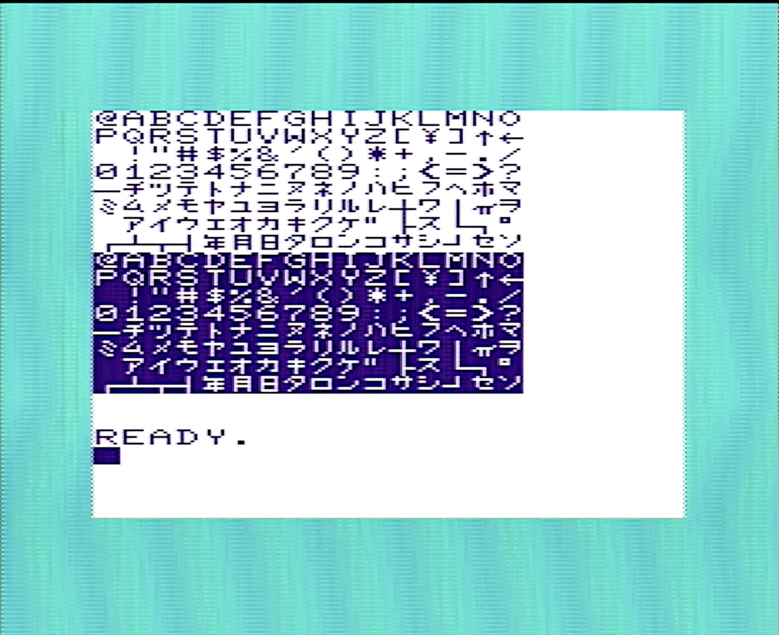
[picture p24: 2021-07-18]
Rev. 0/Pictures/JP_Char_VIC20.png

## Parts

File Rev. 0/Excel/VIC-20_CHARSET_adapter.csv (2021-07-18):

Qty | Value | Device | Package | Parts | Description
1 |  | CLOSED | CP_CL | JP2 | Closed Cutpad
1 |  | OPEN | CP_OP | JP3 | open Cutpad
4 | 10k | R-0805 | 0805 | R1, R2, R3, R4
1 | 2332 | 2332 | DIL24_SOCKET | IC2
1 | COMBI-5X2P | COMBI-5X2P | COMBI-5X2 | JP1
1 | M27C512-DIP28 | M27C512-DIP28 | DIL28-6 | IC1
1 | OPEN_SOURCE_HW | OPEN_SOURCE_HW | OPENHW | U$6

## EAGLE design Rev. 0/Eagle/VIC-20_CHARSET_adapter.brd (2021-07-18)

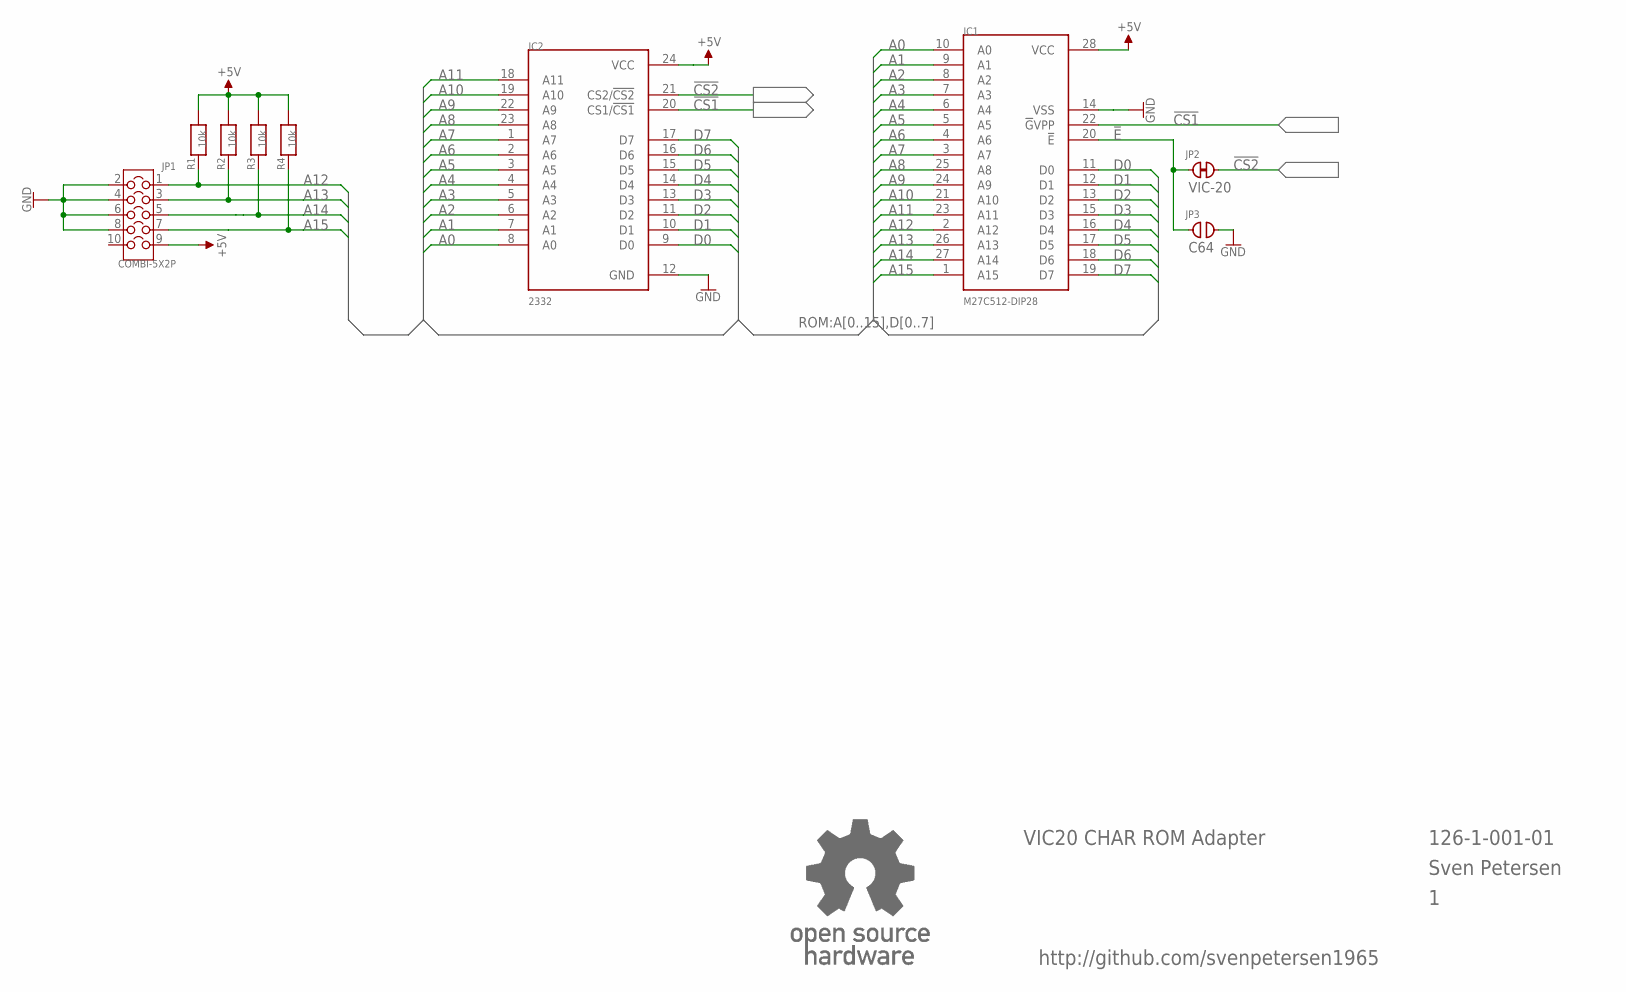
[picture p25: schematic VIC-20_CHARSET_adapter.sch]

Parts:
IC1: M27C512-DIP28; DIL28-6
IC2: 2332; DIL24_SOCKET
JP1: COMBI-5X2P; COMBI-5X2
JP2: CLOSED; CP_CL
JP3: OPEN; CP_OP
R1, R2, R3, R4: 10k; 0805
U$6: OPEN_SOURCE_HW; OPENHW

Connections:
!CS1: IC1.22 (!G!VPP), IC2.20 (CS1/!CS1)
!CS2: IC2.21 (CS2/!CS2), JP2.2
!E: IC1.20 (!E), JP2.1, JP3.1
+5V: IC1.28 (VCC), IC2.24 (VCC), JP1.9, R1.2, R2.2, R3.2, R4.2
A0: IC1.10 (A0), IC2.8 (A0)
A1: IC1.9 (A1), IC2.7 (A1)
A2: IC1.8 (A2), IC2.6 (A2)
A3: IC1.7 (A3), IC2.5 (A3)
A4: IC1.6 (A4), IC2.4 (A4)
A5: IC1.5 (A5), IC2.3 (A5)
A6: IC1.4 (A6), IC2.2 (A6)
A7: IC1.3 (A7), IC2.1 (A7)
A8: IC1.25 (A8), IC2.23 (A8)
A9: IC1.24 (A9), IC2.22 (A9)
A10: IC1.21 (A10), IC2.19 (A10)
A11: IC1.23 (A11), IC2.18 (A11)
A12: IC1.2 (A12), JP1.1, R1.1
A13: IC1.26 (A13), JP1.3, R2.1
A14: IC1.27 (A14), JP1.5, R3.1
A15: IC1.1 (A15), JP1.7, R4.1
D0: IC1.11 (D0), IC2.9 (D0)
D1: IC1.12 (D1), IC2.10 (D1)
D2: IC1.13 (D2), IC2.11 (D2)
D3: IC1.15 (D3), IC2.13 (D3)
D4: IC1.16 (D4), IC2.14 (D4)
D5: IC1.17 (D5), IC2.15 (D5)
D6: IC1.18 (D6), IC2.16 (D6)
D7: IC1.19 (D7), IC2.17 (D7)
GND: IC1.14 (VSS), IC2.12 (GND), JP1.2, JP1.4, JP1.6, JP1.8, JP3.2

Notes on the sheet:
126-1-001-01
Sven Petersen
VIC20 CHAR ROM Adapter
http://github.com/svenpetersen1965
VIC-20
C64

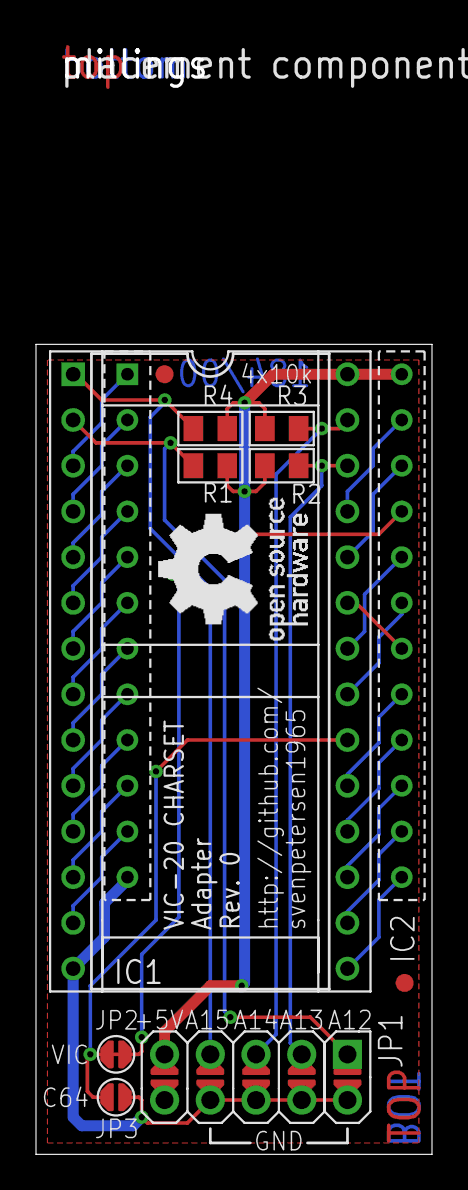
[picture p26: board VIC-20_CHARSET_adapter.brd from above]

Board: 2 copper layers, 22.0 x 45.0 mm, 16 parts (1 on the bottom side), 29 nets.

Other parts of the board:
U$11: SVEN_TAG
U$16: GS28P
U$17, U$18: SMD_REF_R1MM
U$19: 2LAYER
U$20: PCB-TITLE/
